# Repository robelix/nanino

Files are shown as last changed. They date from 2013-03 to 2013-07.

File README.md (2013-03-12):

nanino rlx
==========

my variant of the nanino - a DIY friendly arduino clone

* pin-compatible with arduino shields
* DIY friendly single sided PCB
* FTDI connector
* prototyping area

based on nanoino by Johan von Konow  
http://vonkonow.com/wordpress/2012/10/nanino-the-diy-friendly-arduino/

License: [Creative Commons BY-NC-SA 3.0](http://creativecommons.org/licenses/by-nc-sa/3.0/)

## Changes in Version 1.1:
* Rx/Tx of FTDI corrected
* bigger solder pads

nanino rlx
nanino rlx pcb
nanino rlx scheme

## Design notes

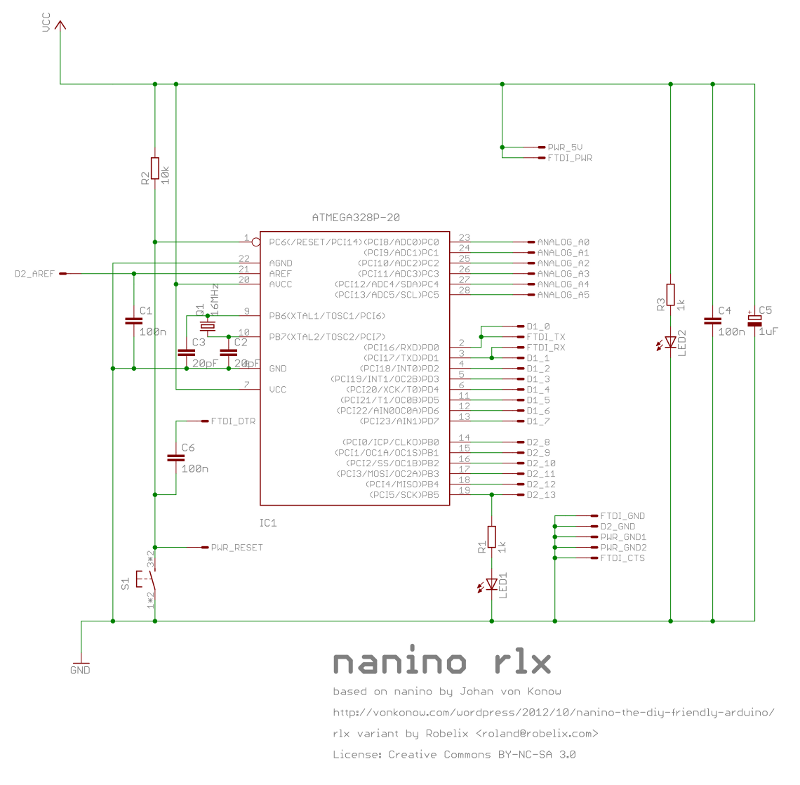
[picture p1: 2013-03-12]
eagle/nanino-scheme.png

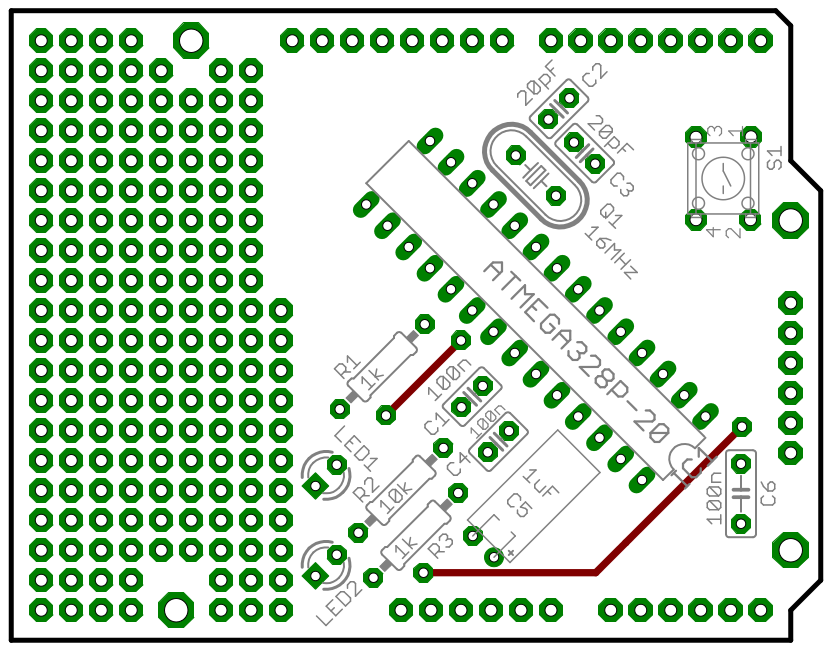
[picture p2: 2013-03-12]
eagle/nanino.png

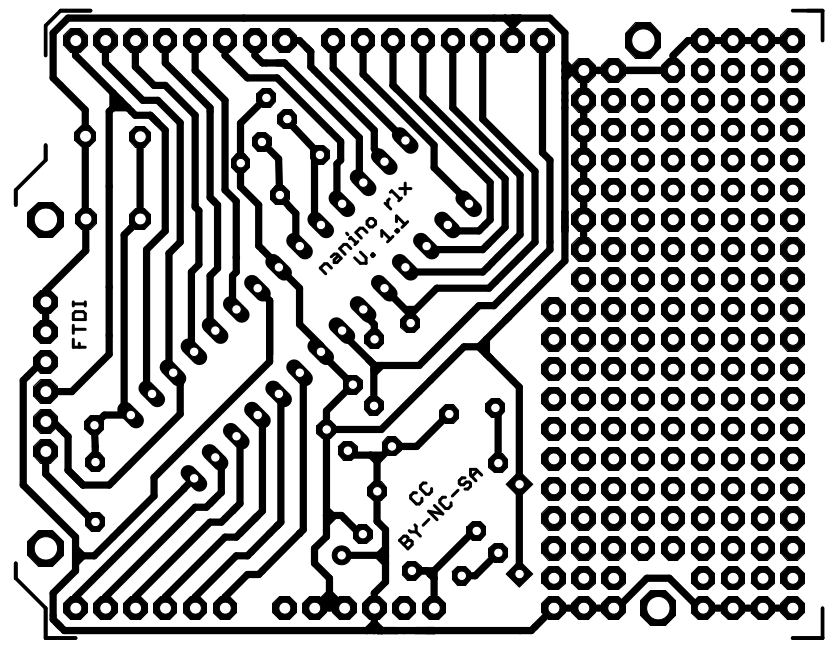
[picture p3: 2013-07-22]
eagle/nanino-pcb.png

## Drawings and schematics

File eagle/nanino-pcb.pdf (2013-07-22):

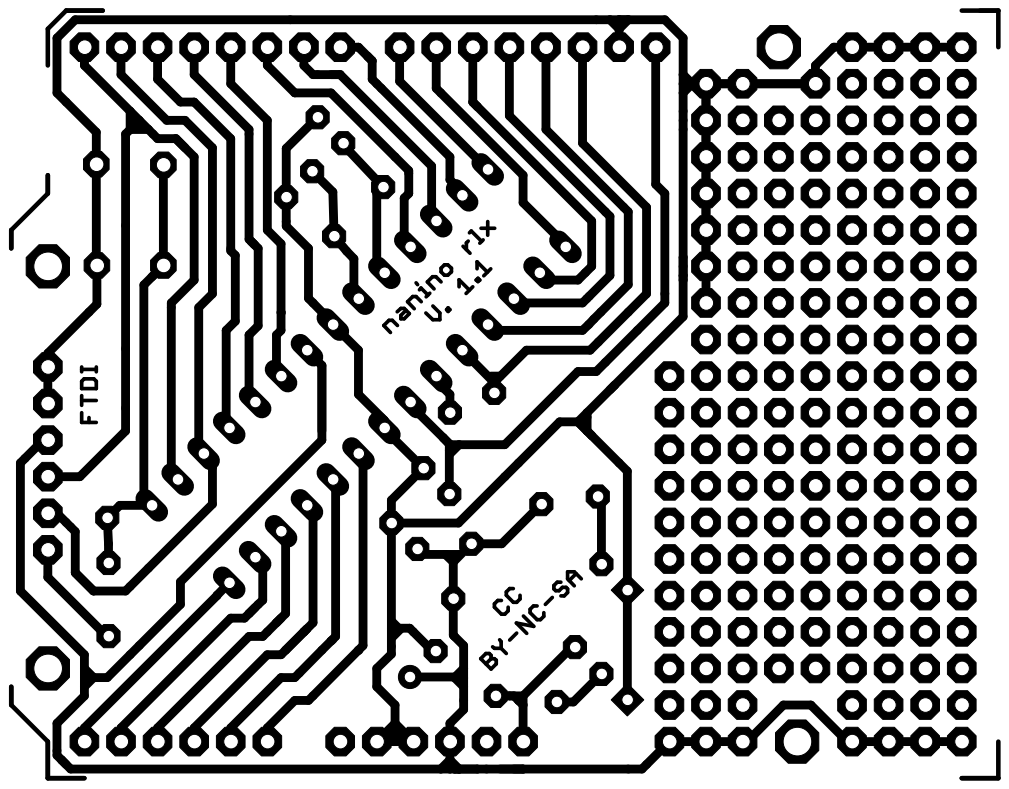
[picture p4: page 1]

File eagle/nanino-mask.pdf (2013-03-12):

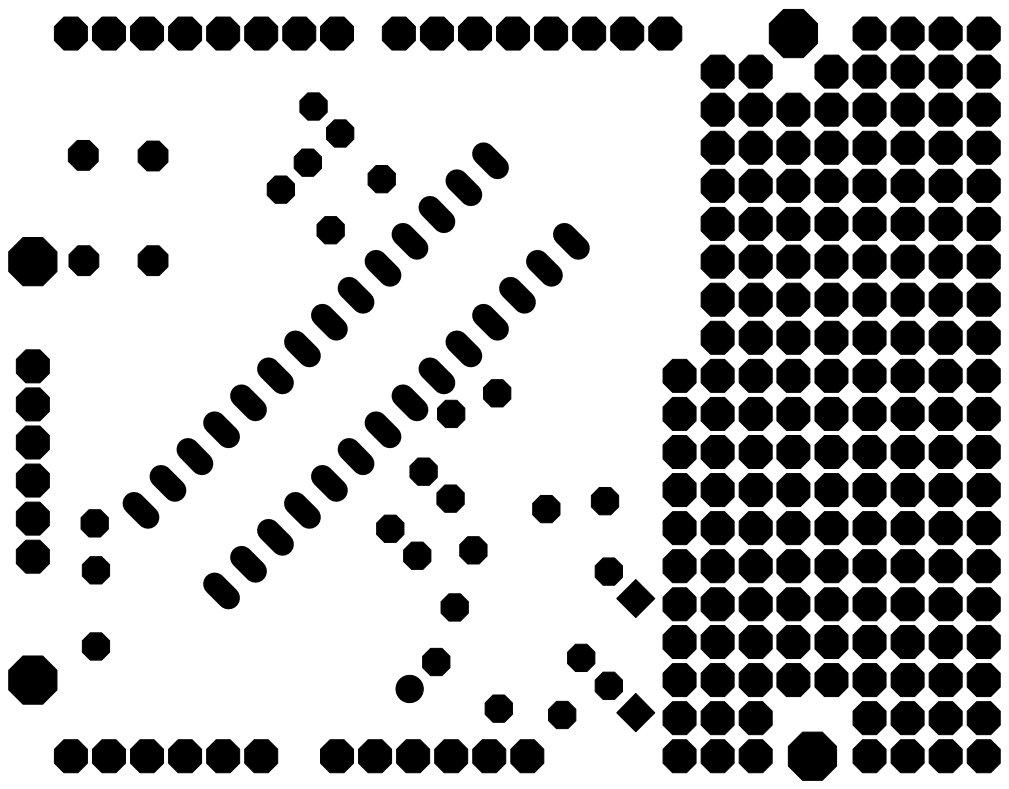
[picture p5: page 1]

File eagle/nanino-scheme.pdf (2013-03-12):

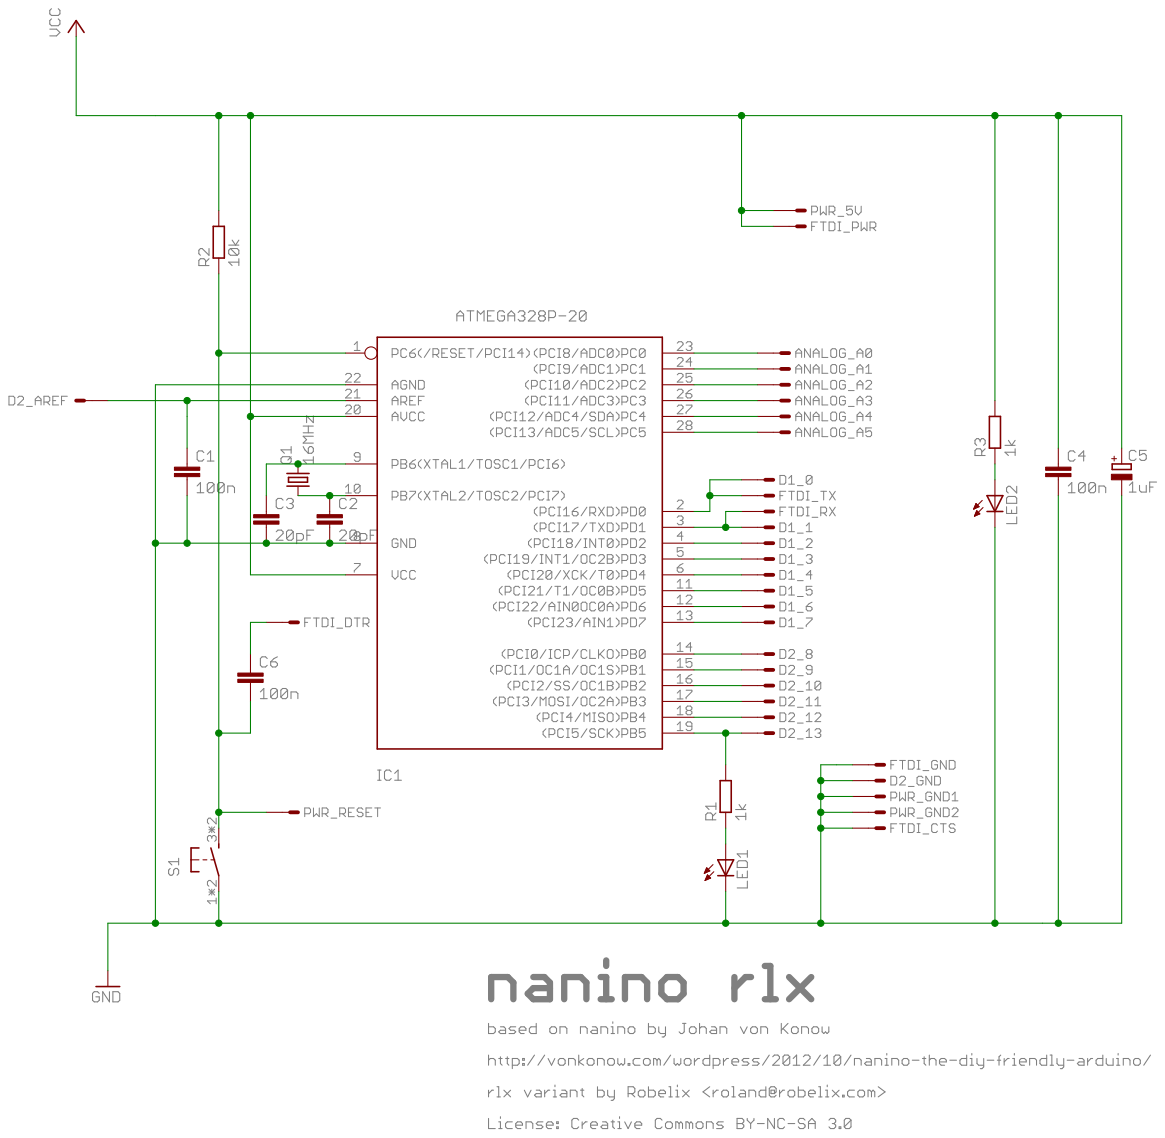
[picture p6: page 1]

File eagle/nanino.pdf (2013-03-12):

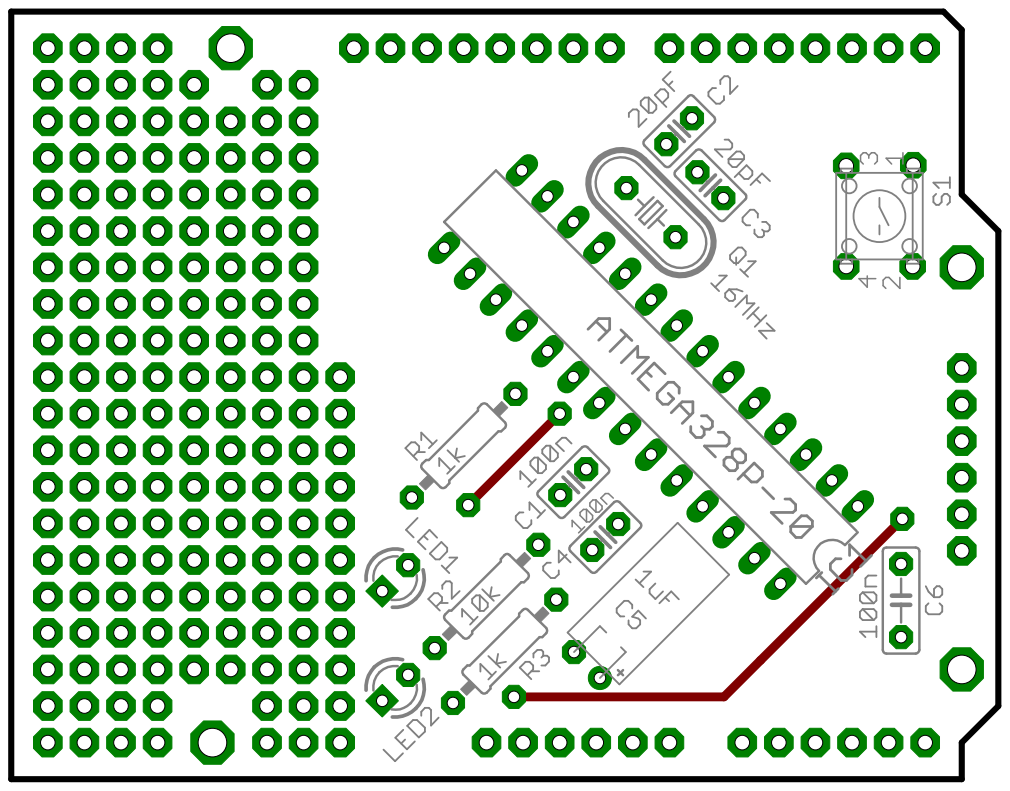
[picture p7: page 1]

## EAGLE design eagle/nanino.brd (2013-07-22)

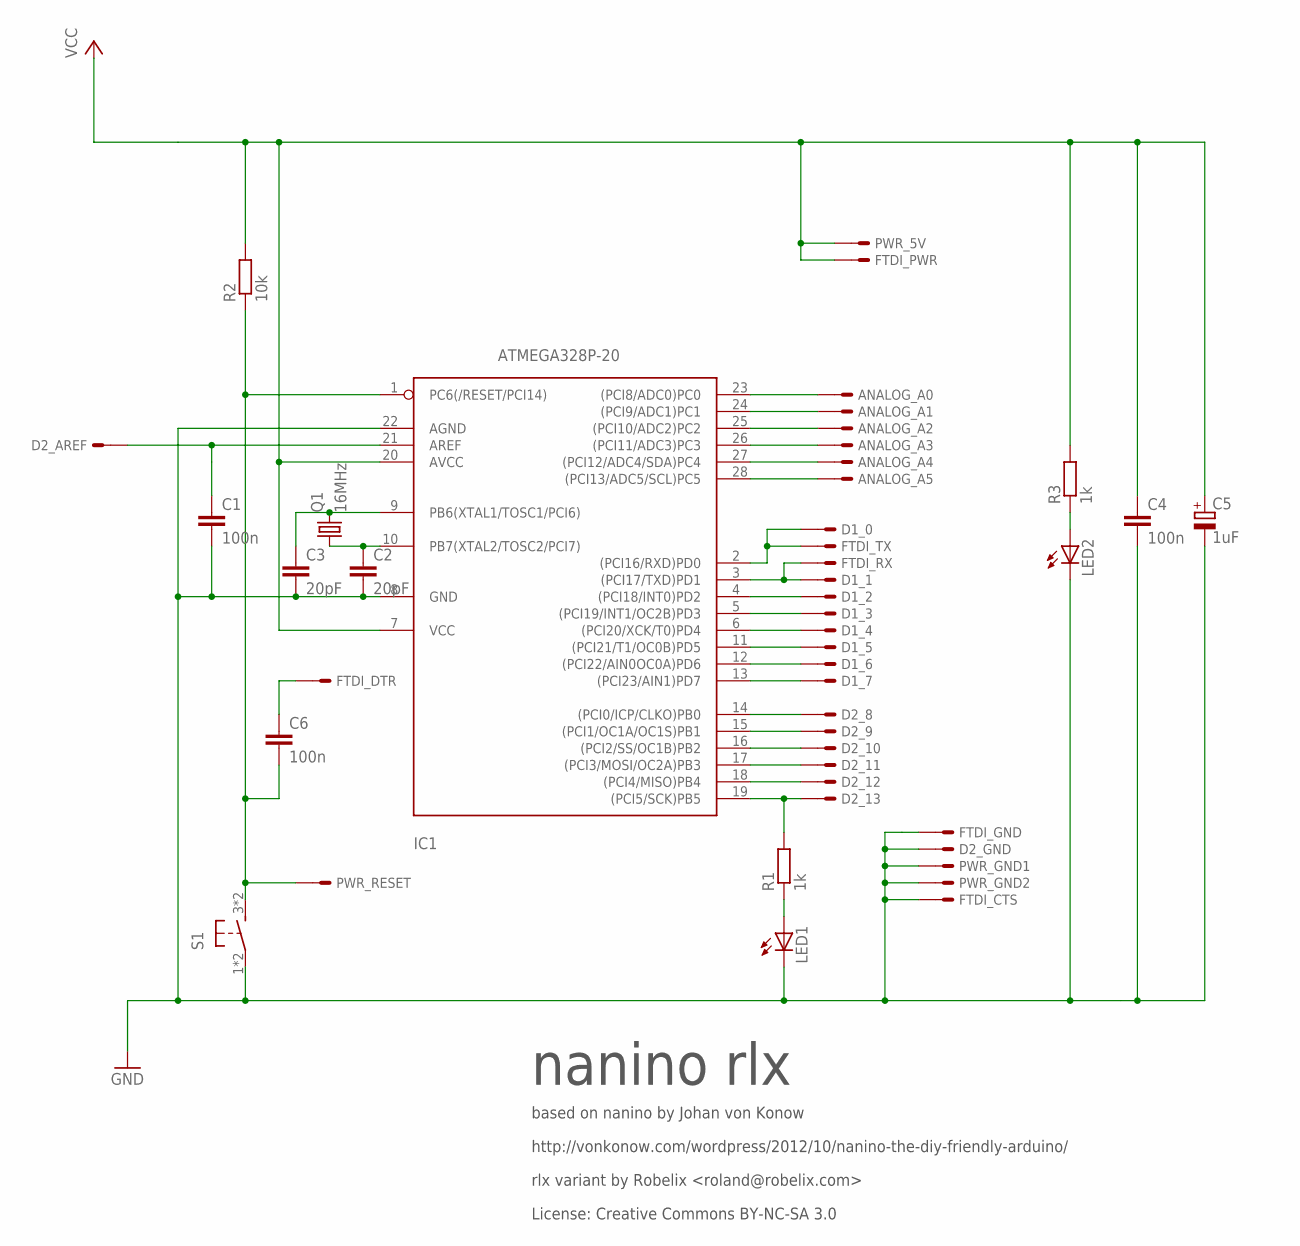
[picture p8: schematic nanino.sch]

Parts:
ANALOG_: PINS_ARDUINO_ANALOG1; 6PIN
C1, C4: 100n; C025-025X050
C2, C3: 20pF; C025-025X050
C5: 1uF; E2,5-5-L-12
C6: 100n; C050-025X075
D1_: PINS_ARDUINO_DIGITAL1; 8PIN
D2_: PINS_ARDUINO_DIGITAL2; 8PIN
FTDI_: PINS_FTDI1; 6PIN
IC1: ATMEGA328P-20; DIL28-3
LED1, LED2: LED3MM
PWR_: PINS_ARDUINO_PWR1; 6PIN
Q1: 16MHz; HC49U-V
R1, R3: 1k; 0207/10
R2: 10k; 0207/10
S1: TASTER4.3MM; TASTER6X6

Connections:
GND: C1.2, C2.2, C3.2, C4.2, C5.-, D2_.7, FTDI_.1, FTDI_.2, IC1.8 (GND), IC1.22 (AGND), LED1.K (C), LED2.K (C), PWR_.4, PWR_.5, S1.1, S1.2 (1)
unnamed: D1_.1, FTDI_.4, IC1.2 ((PCI16/RXD)PD0)
unnamed: D1_.2, FTDI_.5, IC1.3 ((PCI17/TXD)PD1)
unnamed: D1_.3, IC1.4 ((PCI18/INT0)PD2)
unnamed: D1_.4, IC1.5 ((PCI19/INT1/OC2B)PD3)
unnamed: D1_.5, IC1.6 ((PCI20/XCK/T0)PD4)
unnamed: D1_.6, IC1.11 ((PCI21/T1/OC0B)PD5)
unnamed: D1_.7, IC1.12 ((PCI22/AIN0OC0A)PD6)
unnamed: D1_.8, IC1.13 ((PCI23/AIN1)PD7)
unnamed: D2_.1, IC1.14 ((PCI0/ICP/CLKO)PB0)
unnamed: D2_.2, IC1.15 ((PCI1/OC1A/OC1S)PB1)
unnamed: D2_.3, IC1.16 ((PCI2/SS/OC1B)PB2)
unnamed: D2_.4, IC1.17 ((PCI3/MOSI/OC2A)PB3)
unnamed: D2_.5, IC1.18 ((PCI4/MISO)PB4)
unnamed: D2_.6, IC1.19 ((PCI5/SCK)PB5), R1.2
unnamed: LED1.A, R1.1
unnamed: ANALOG_.6, IC1.23 ((PCI8/ADC0)PC0)
unnamed: ANALOG_.5, IC1.24 ((PCI9/ADC1)PC1)
unnamed: ANALOG_.4, IC1.25 ((PCI10/ADC2)PC2)
unnamed: ANALOG_.3, IC1.26 ((PCI11/ADC3)PC3)
unnamed: ANALOG_.2, IC1.27 ((PCI12/ADC4/SDA)PC4)
unnamed: ANALOG_.1, IC1.28 ((PCI13/ADC5/SCL)PC5)
unnamed: C6.2, IC1.1 (PC6(/RESET/PCI14)), PWR_.1, R2.1, S1.3, S1.4 (3)
unnamed: LED2.A, R3.1
unnamed: C1.1, D2_.8, IC1.21 (AREF)
unnamed: C3.1, IC1.9 (PB6(XTAL1/TOSC1/PCI6)), Q1.2
unnamed: C2.1, IC1.10 (PB7(XTAL2/TOSC2/PCI7)), Q1.1
unnamed: C6.1, FTDI_.6
VCC: C4.1, C5.+, FTDI_.3, IC1.7 (VCC), IC1.20 (AVCC), PWR_.3, R2.2, R3.2

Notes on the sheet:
nanino rlx
based on nanino by Johan von Konow
http://vonkonow.com/wordpress/2012/10/nanino-the-diy-friendly-arduino/
rlx variant by Robelix <roland@robelix.com>
License: Creative Commons BY-NC-SA 3.0

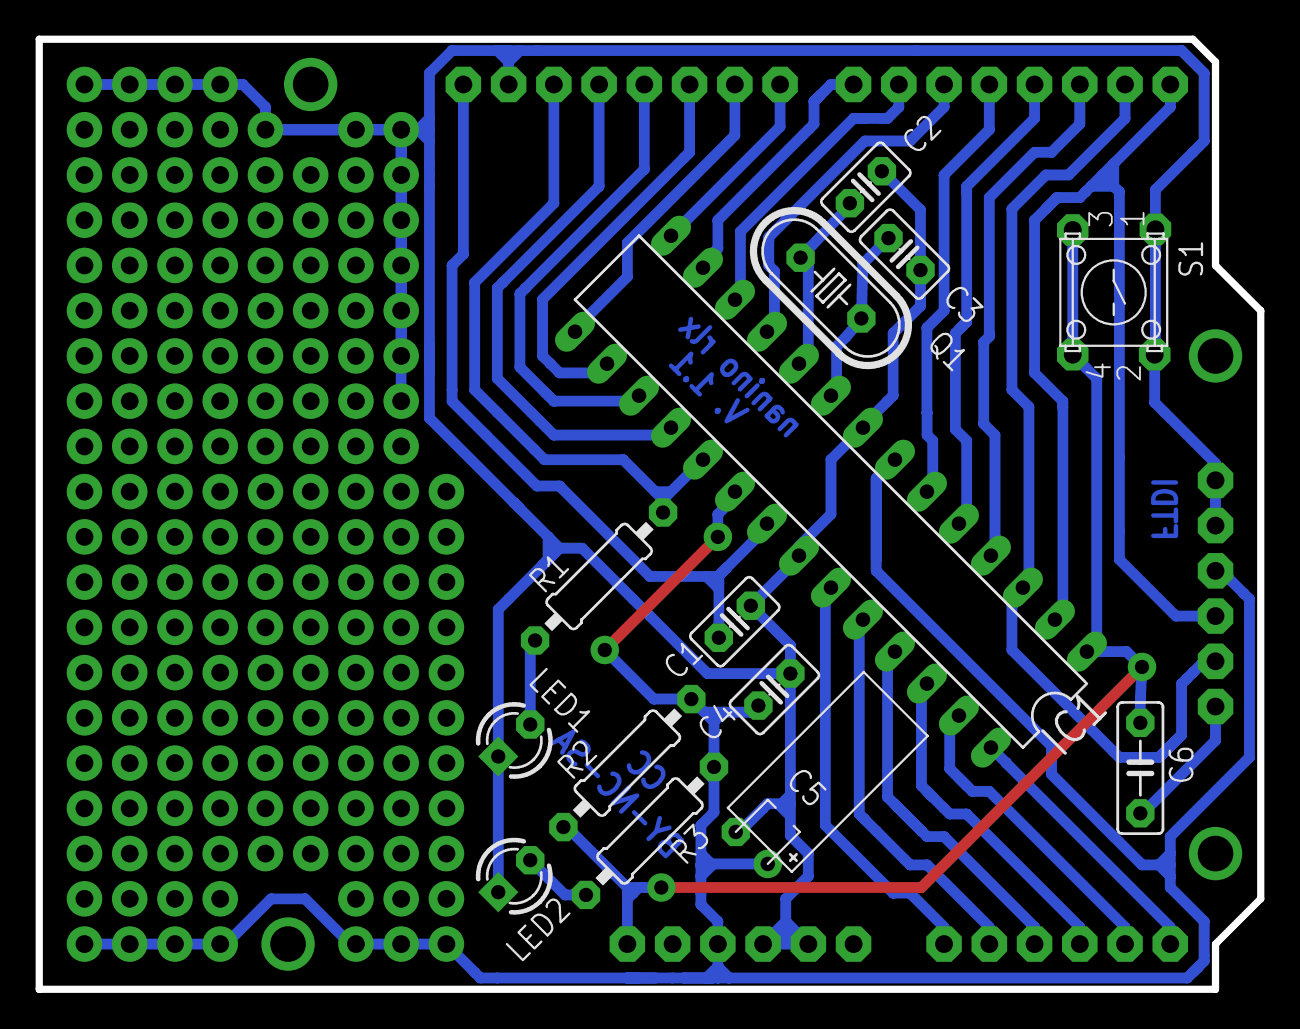
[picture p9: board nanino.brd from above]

Board: 2 copper layers, 68.6 x 53.3 mm, 19 parts (0 on the bottom side), 29 nets.

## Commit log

2013-02-09 initial upload
    [nanino.brd, nanino.sch]
2013-02-15 improved routing
    [nanino.brd, nanino.sch]
2013-03-12 Version 1.1 - FTDI Rx/Tx corrected, bigger solder pads
    [nanino.brd, nanino.sch]
2013-07-22 Power was connected to 3.3V Pin, not to 5V
    [nanino.brd, nanino.sch]
2013-07-22 5V power was connected to 3.3V Pin
    [nanino.brd, nanino.sch]
